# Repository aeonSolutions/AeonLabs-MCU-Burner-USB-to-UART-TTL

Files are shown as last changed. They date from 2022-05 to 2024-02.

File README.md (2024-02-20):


  
 
 

<a href="https://trackgit.com">
trackgit-views
</a>




[](https://www.buymeacoffee.com/migueltomas)
<a href="https://github.com/sponsors/aeonSolutions">
   
</a>

[PCB-Prototyping-Catalogue](https://github.com/aeonSolutions/PCB-Prototyping-Catalogue)  >>  [DIY & Maker](https://github.com/aeonSolutions/PCB-Prototyping-Catalogue/blob/main/DIY-Maker/README.md)  >> MCU Burner USB to UART TTL

<p align="right">
 <a href="https://github-com.translate.goog/aeonSolutions/PCB-Prototyping-Catalogue/tree/main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">Change Language</a> <br>
Last update: 17-2-2024
</p>

<br />

# AeonLabs MCU Burner USB to UART TTL
This repo contains the KiCad files for the micro-USB to UART TTL PCB  or USB to USB for MCUs compatible with direct USB firmware download. This PCB can do firmware download on any AeonLabs PCB designs or any other PCB running at 3.3V or 5.0V.
Features voltage selection : 3.0V 250mA/500mA or 5.0V 500mA and automatic reset and automatic boot. It can fit an enclosure with dimensions of 35x35x4 mm

*Don't forget to LIKE , SHARE and subscribe the free whatsApp group* and if you liked this PCB consider buying me a cup of coffee. Links below.

### Status
 Fully tested and working

<p align="center">
 <a href="https://www.youtube.com/watch?v=EkAStzBm8CE">
    
 </a> <br>
 First Firmware download of AeonLabs's USB to UART TTL Burner
 </p>

## Revisions
- revision 1.4
  - added USB to USB option for MCUs compatible with direct USB firmware donwload
- revision 1.x
  - copper track bug corrections  
  - Voltage selection : 3.0V 250mA/500mA or 5.0V 500mA 
  - MCU firmware downloader with automatic reset and automatic boot. 

## Download options
Download this repository if you need the KiCad Files or, download the Gerber files in the release section of this repository

## Liked it ? Get a Free PCB for yourself
Send me your Device or hardware and i will design a custom PCB for it. Free of charge. Contact-me on WhatsApp or email for more info. 

## Q&A WhatsApp Group
If you have any Questions or simply  like this kind of projects and want to stay updated with the latest research ideas and prototypes during the day and week, join the WhatsApp Group
[LDAD Lab & Prototyping](https://chat.whatsapp.com/FkNC7u83kuy2QRA5sqjBVg)

There are useful answers on stackExchage about this topic i recommed reading. One is [ESP-WROOM-32 layout USB-UART](https://electronics.stackexchange.com/questions/429812/esp-wroom-32-layout-usb-uart/601827#601827) and [ESP32 with FTDI programmer](https://electronics.stackexchange.com/questions/448187/esp32-with-ftdi-programmer/601761#601761)

## Fully assembled PCB
### alternatively, and if you do not want to build a PCB by yourself, you can buy here:
(https://www.tindie.com/stores/aeonlabs/)

The price will be around 30eur plus postage fees.
(I will also deliver the assembled PCB with all the components in place at a fair aditonal cost).
#### Be supportive of my dedication and work towards technology education and buy me a coffee. Link below.

<p align="center">
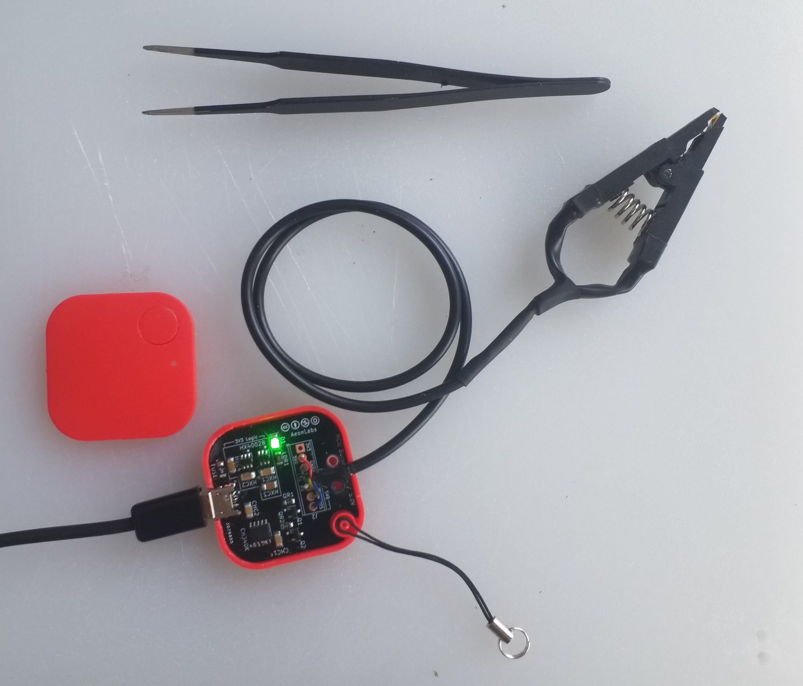
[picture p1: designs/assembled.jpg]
    
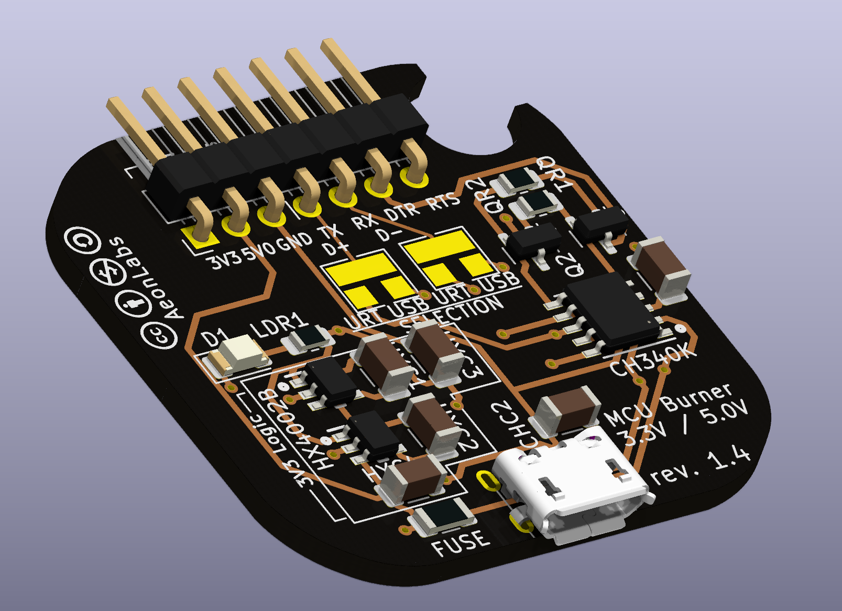
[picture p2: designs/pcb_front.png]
    
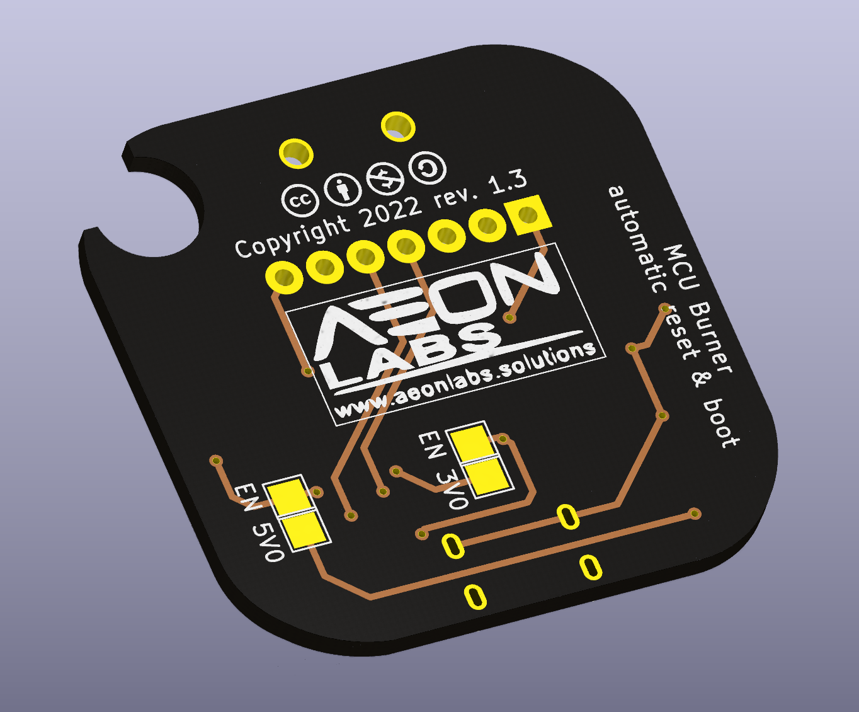
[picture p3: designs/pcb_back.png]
    
</p>

## PCB Parts list
- DC2DC converter HX4002B x2 : https://s.click.aliexpress.com/e/_Ak7IPx
- Capacitor 100nF SMD 1206 : https://s.click.aliexpress.com/e/_AVdmzr
- Capacitor 2.2uF SMD 1206 : https://s.click.aliexpress.com/e/_AVdmzr
- LED SMD 1206 : https://s.click.aliexpress.com/e/_A9THIl
- Resistor SMD 1206 330R : https://s.click.aliexpress.com/e/_A7OXrR
- Programmer Clip : https://s.click.aliexpress.com/e/_A7s5EN
- 6 core wire : https://s.click.aliexpress.com/e/_Atht2d
- Micro USB PCB socket : https://s.click.aliexpress.com/e/_A123KH 

<br />
<br />

## Author

You can get in touch with me on my LinkedIn Profile:

#### Miguel Tomas



<a href="https://stackexchange.com/users/18907312/miguel-silva">profile for Miguel Silva on Stack Exchange, a network of free, community-driven Q&A sites</a>



You can also follow my GitHub Profile to stay updated about my latest projects: 

<br>

**Hire me** <br>
See [here](https://github.com/aeonSolutions/PCB-Prototyping-Catalogue/wiki/How-to-Hire-AeonLabs) how to hire AeonLabs.

<br>

### Be supportive of my dedication and work towards technology education and buy me a cup of coffee
The PCB design Files I provide here for anyone to use are free. If you like this Smart Device or use it, please consider buying me a cup of coffee, a slice of pizza or a book to help me study, eat and think new PCB design files.

<p align="center">
    <a href="https://www.buymeacoffee.com/migueltomas">
        
    </a>
</p>

### Make a donation on PayPal
Make a donation on PayPal and get a TAX refund*.

<p align="center">
    <a href="http://paypal.me/mtpsilva">
        
    </a>
</p>

### Support all these open hardware projects and become a GitHub sponsor  
Liked any of my PCB KiCad Designs? Help and Support my open work to all by becoming a GitHub sponsor.

<p align="center">
    <a href="https://github.com/aeonSolutions/PCB-Prototyping-Catalogue/blob/main/become_a_sponsor/aeonlabs-github-sponsorship-agreement.docx">
        
    </a>
    <a href="https://github.com/sponsors/aeonSolutions">
        
    </a>
</p>

# 

### License

Before proceeding to download any of AeonLabs software solutions for open-source development and/or PCB hardware electronics development make sure you are choosing the right license for your project. See [AeonLabs Solutions for Open Hardware & Source Development](https://github.com/aeonSolutions/PCB-Prototyping-Catalogue/wiki/AeonLabs-Solutions-for-Open-Hardware-&-Source-Development) for more information.

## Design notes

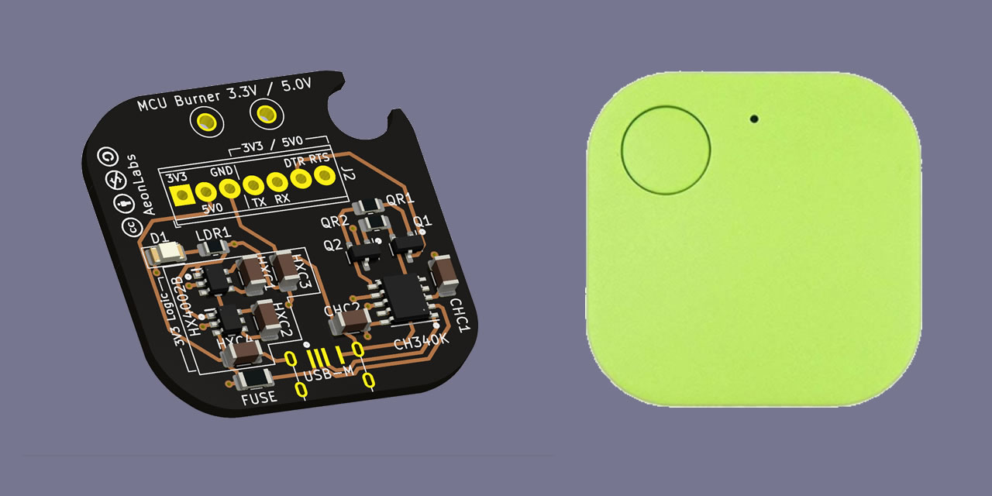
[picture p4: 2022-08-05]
designs/pcb.jpg

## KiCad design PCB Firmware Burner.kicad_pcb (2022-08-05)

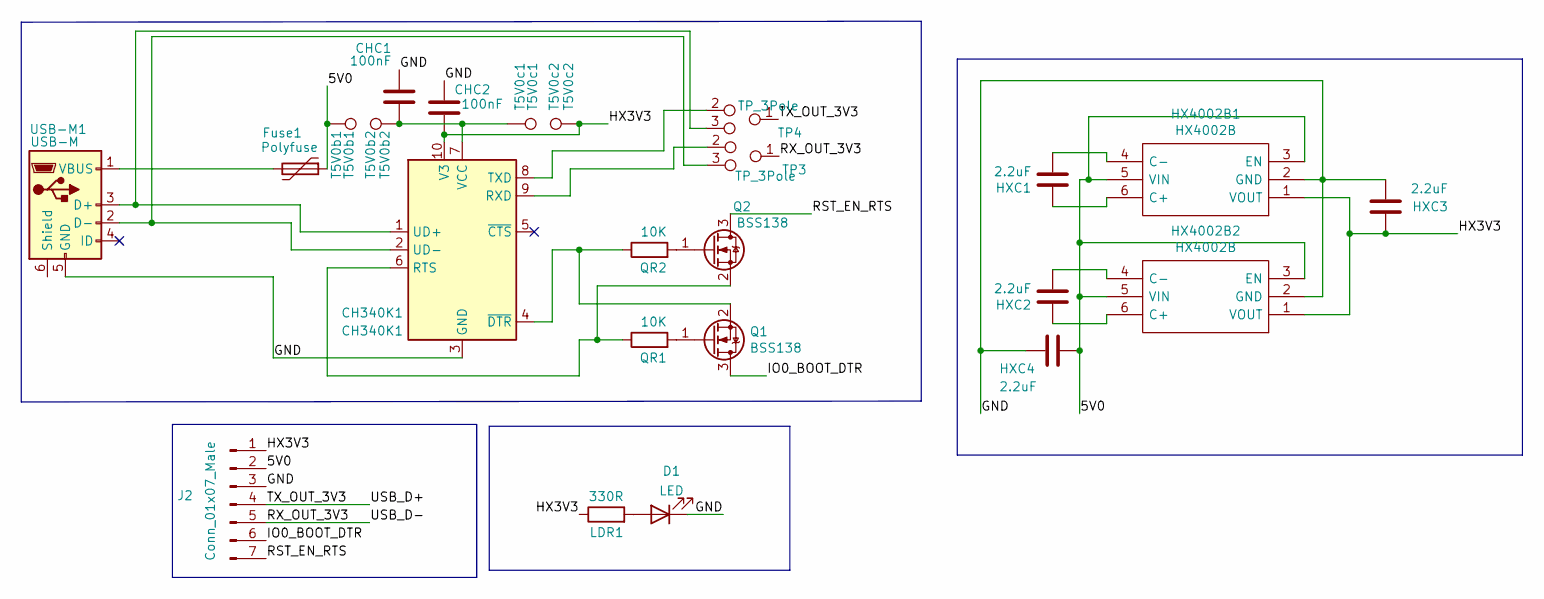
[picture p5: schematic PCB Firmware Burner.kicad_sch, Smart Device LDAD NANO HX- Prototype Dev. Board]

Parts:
CH340K1: CH340K1; SSOP-10_3.9x4.9mm_P1.00mm
CHC1, CHC2: 100nF; C_1206_3216Metric
D1: LED; LED_1206_3216Metric
Fuse1: Polyfuse; Fuse_1206_3216Metric
HX4002B1, HX4002B2: HX4002B; HX4002 SOT95 P280X125-6N; Manufacturer_Part_Number HX4002
HXC1, HXC2, HXC3, HXC4: 2.2uF; C_1206_3216Metric
J2: Conn_01x07_Male; PinHeader_1x07_P2.54mm_Horizontal
LDR1: 330R; R_0805_2012Metric_Pad1.20x1.40mm_HandSolder
Q1, Q2: BSS138; SOT-23
QR1, QR2: 10K; R_0805_2012Metric_Pad1.20x1.40mm_HandSolder
T5V0b1: T5V0b1; TestPoint_Pad_2.0x2.0mm
T5V0b2: T5V0b2; TestPoint_Pad_2.0x2.0mm
T5V0c1: T5V0c1; TestPoint_Pad_2.0x2.0mm
T5V0c2: T5V0c2; TestPoint_Pad_2.0x2.0mm
TP3, TP4: TP_3Pole; TestPoint_Pad_1.5mm 3 points
USB-M1: USB-M; Micro_USB_pcb_socket_5pin_4weld_points

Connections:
/5V0: Fuse1.1, HX4002B1.3 (EN), HX4002B1.5 (VIN), HX4002B2.3 (EN), HX4002B2.5 (VIN), HXC4.1, J2.2, T5V0b1.1
/GND: CH340K1.3 (GND), CHC1.2, CHC2.2, D1.1 (K), HX4002B1.2 (GND), HX4002B2.2 (GND), HXC3.2, HXC4.2, J2.3, USB-M1.5 (GND)
/HX3V3: CH340K1.10 (V3), CHC2.1, HX4002B1.1 (VOUT), HX4002B2.1 (VOUT), HXC3.1, J2.1, LDR1.1, T5V0c2.1
/IO0_BOOT_DTR: J2.6, Q1.3 (D)
/RST_EN_RTS: J2.7, Q2.3 (D)
/RX_OUT_3V3: J2.5, TP3.1
/TX_OUT_3V3: J2.4, TP4.1
unnamed: CH340K1.2 (UD-), TP3.3, USB-M1.2 (D-)
unnamed: CH340K1.4 (~DTR), Q1.2 (S), QR2.1
unnamed: CH340K1.6 (RTS), Q2.2 (S), QR1.1
unnamed: CH340K1.7 (VCC), CHC1.1, T5V0b2.1, T5V0c1.1
unnamed: CH340K1.8 (TXD), TP4.2
unnamed: CH340K1.9 (RXD), TP3.2
unnamed: D1.2 (A), LDR1.2
unnamed: Fuse1.2, USB-M1.1 (VBUS)
unnamed: HX4002B1.4 (C-), HXC1.2
unnamed: HX4002B1.6 (C+), HXC1.1
unnamed: HX4002B2.4 (C-), HXC2.2
unnamed: HX4002B2.6 (C+), HXC2.1
unnamed: Q1.1 (G), QR1.2
unnamed: Q2.1 (G), QR2.2
unnamed: CH340K1.1 (UD+), TP4.3, USB-M1.3 (D+)

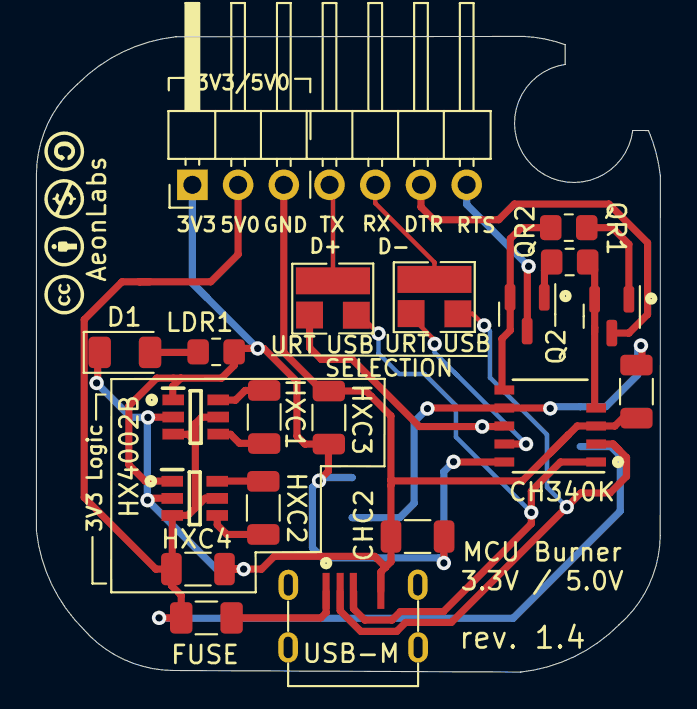
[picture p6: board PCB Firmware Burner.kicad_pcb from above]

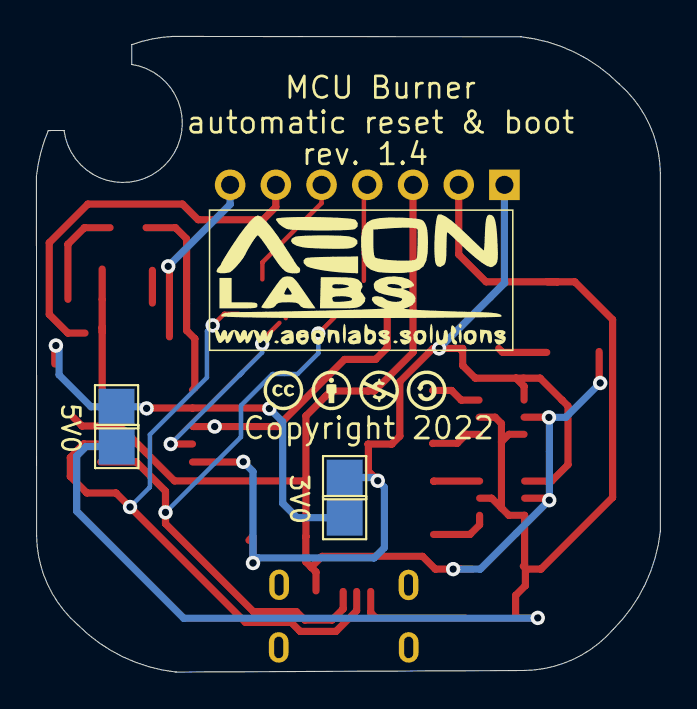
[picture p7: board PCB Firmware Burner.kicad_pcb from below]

Board: 2 copper layers, 34.7 x 35.3 mm, 24 parts (4 on the bottom side), 22 nets.

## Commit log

2022-03-28 first upload
    [PCB Firmware Burner.kicad_pcb, PCB Firmware Burner.kicad_sch, PCB Firmware Burner.sch]
2022-03-30 revision 1.1
    [PCB Firmware Burner.kicad_pcb, PCB Firmware Burner.kicad_sch]
2022-03-30 revision 1.2
    possibility of voltage selection: 3V3 or 5V0
    [PCB Firmware Burner.kicad_pcb, PCB Firmware Burner.kicad_sch]
2022-05-28 revision 1,3
    Track bug corrections
    [PCB Firmware Burner.kicad_pcb]
2022-08-05 rev 1.4
    [PCB Firmware Burner.kicad_pcb, PCB Firmware Burner.kicad_sch]

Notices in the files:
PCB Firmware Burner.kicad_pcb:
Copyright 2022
